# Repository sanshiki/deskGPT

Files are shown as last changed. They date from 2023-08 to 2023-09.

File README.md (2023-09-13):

# 嵌入式高级实验作业：智能桌宠deskGPT

## 项目介绍

### 简介

本项目是浙江大学嵌入式高级实验课程项目，内容为基于stm32的AI智能桌宠deskGPT，能够实现识别用户语音，并转为文字，通过基于chatGPT3.5的大语言模型AI，实现对用户语音的智能回复，并合成语音，通过扬声器播放。

### 模块介绍

#### 下位机

下位机MCU我们采用stm32f407zgt6，使用cubemx+keil5进行编程。录音以及播放模块采用vs1053模块。

#### 上位机

上位机程序我们使用python3.11.4，语音识别（iat）与语音合成（tts）我们采用科大讯飞的web接口，AI模块我们使用的是chatanywhere的开源项目，参考https://github.com/chatanywhere/GPT_API_free.git。

## 依赖安装

### 安装方法

```bash
pip install <package-name>
```

**注意：pywt的安装方法为 `pip install PyWavelets`**

### python第三方库

websocket、numpy、pyusb、openai、pywt、scipy

## 更新日志

23.7.14：建立项目仓库

嵌入式部分：基本参照https://blog.csdn.net/weixin_44226356/article/details/125153210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,239^v2^insert_chatgpt&spm=1018.2226.3001.4187

经测试发现usb_cdc在发送时字节会翻转，故写了一个byteSwap函数

上位机serial：主要是使用了python自带的pyserial库。安装：

```bash
pip install pyserial
```

串口封装为usb_cdc库。

UI部分使用tkinter，还未完成

文件读写封装为fileIO库，主要用的就是pcmFileManager

**已实现的功能**：usb_cdc串口收发，i2s收发，保存为pcm文件

**待解决的问题**：pcm文件的数据不知道正不正确，经过网上找的pcm播放器放出来全是噪音，无法做进一步的滤波处理。

相关csdn链接：
example:https://blog.csdn.net/Laura_Luo/article/details/117779052?spm=1001.2014.3001.5506
usb_cdc:https://blog.csdn.net/zhanglifu3601881/article/details/89441412?spm=1001.2014.3001.5506
inmp441:https://blog.csdn.net/qq_15181569/article/details/131224833?spm=1001.2014.3001.5506
vm8978:https://blog.csdn.net/banzhuan133/article/details/78610883/?spm=1001.2014.3001.5506
i2s:https://blog.csdn.net/Q_Lee/article/details/131217760?spm=1001.2014.3001.5506

23.7.20

usb通信改为使用pyusb库

解决pcm数据格式问题，成功播放出inmp441的录音，但是噪声较大。

尝试过采用带通滤波、小波变换等滤波方法，最后采用小波变换。

经过测试，usb传输数据遗漏严重，暂时不知道如何解决。

科大讯飞的iat、tts模块以及chatGPT api接入均已完成。

23.8：完善项目

解决了usb传输数据遗漏的问题，从单次发送少量数据，快速发送的模式改为单次发送大量数据，降低发送频率，成功解决了数据发送的问题。

基于此，为上下位机编写了数据包以及解包方式。数据包包括用于检测数据的数据头、下位机控制字以及音频数据。

inmp441效果不好，改为使用vs1053，参考正点原子的原代码进行驱动。

成功实现vs1053的录音和播放问题，并且成功串联从录音、iat、tts到播放的模块。

存在问题：vs1053在录音时会播放录到的音频，并且噪声很大。第一次上电时无法正常工作。

23.9

查资料发现，可以通过修改vs1053的SCI_VOL寄存器来使得录音时不播放，但是正点原子例程的atk_mo1053_set_volume修改不了。

后来发现通过修改sram可以实现。参考博客：http://www.openedv.com/posts/list/14900.htm

在上位机初始化之后，提前发送几个进入录音模式的空数据包，能够解决第一次上电无法工作的问题。

成功串联chatGPT模块，并且使程序流程可以循环。

存在问题：合成的语音没有电流声，但是播放时存在电流声。初步猜测是传输间隔的问题。目前的传输间隔由sleep控制，过于粗糙。

Emoji文件夹需要使用opencv编译，能够产生二进制视频文件(240*240*3).

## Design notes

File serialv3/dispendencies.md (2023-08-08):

# 科大讯飞iat & tts接口环境配置

## 依赖库

- websocket

## 存在问题

* 报错：`AttributeError: module 'websocket' has no attribute 'enableTrace'`
*

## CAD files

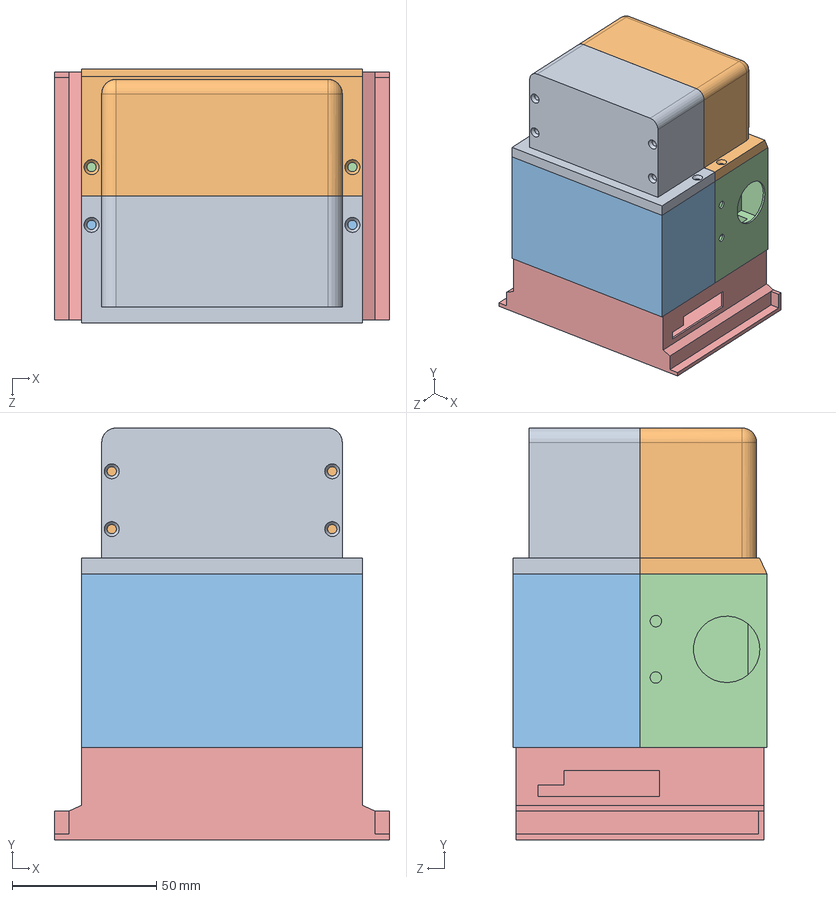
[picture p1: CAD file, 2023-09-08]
3dprint/小对立.SLDASM
116.0 x 142.6 x 88.0 mm
deskGPT底座-stm32
deskGPT中间壳
deskGPT中间壳2
deskGPT头-oled-part1
deskGPT头-part2

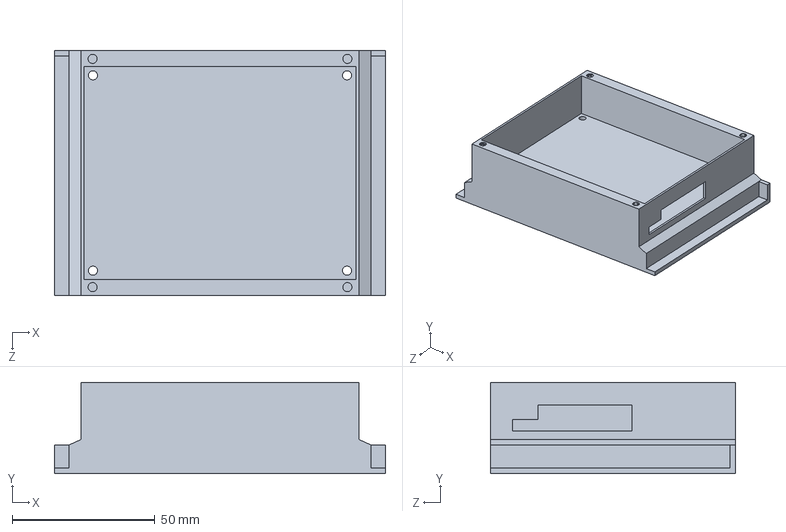
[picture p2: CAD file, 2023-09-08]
3dprint/deskGPT底座-stm32.SLDPRT
116.0 x 32.0 x 86.0 mm

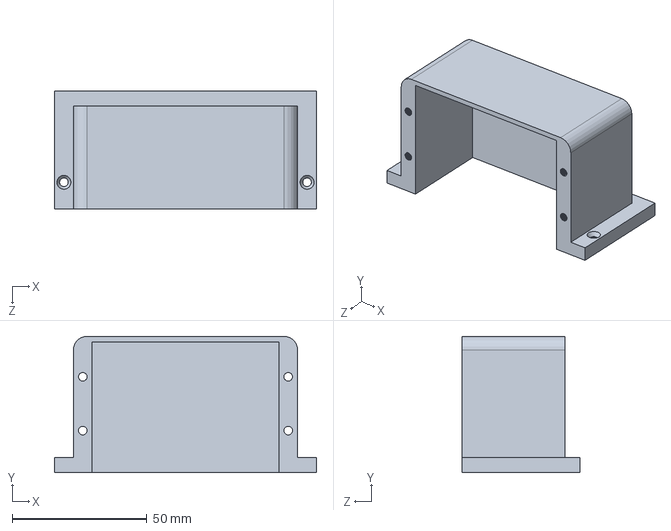
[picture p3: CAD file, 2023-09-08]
3dprint/deskGPT头-part2.SLDPRT
97.3 x 50.6 x 44.0 mm

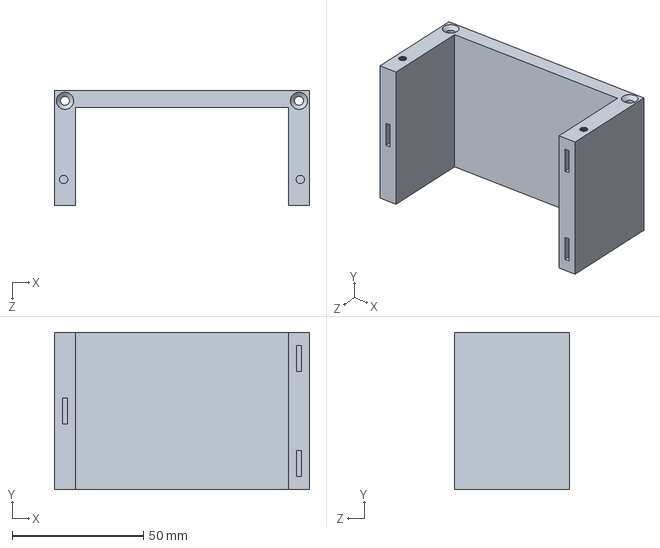
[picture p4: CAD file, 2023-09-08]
3dprint/deskGPT中间壳2.SLDPRT
97.3 x 60.0 x 44.0 mm

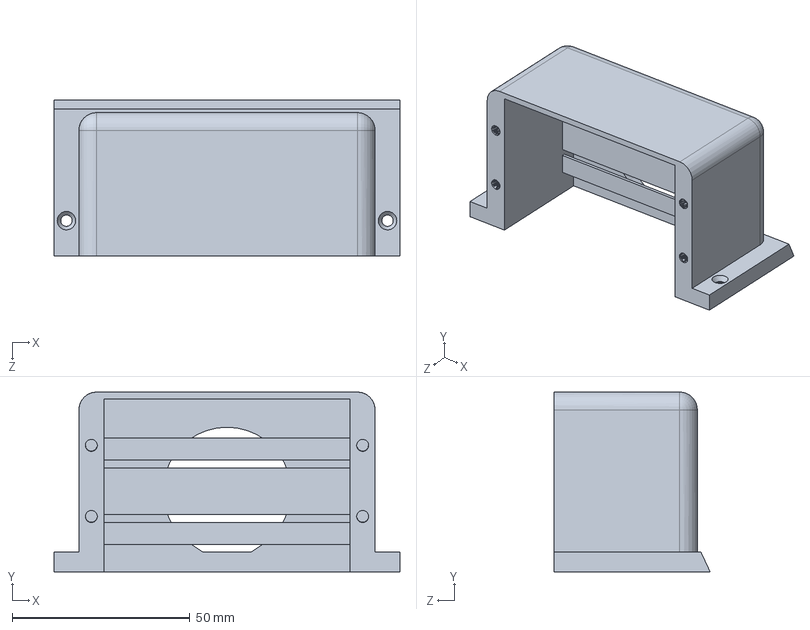
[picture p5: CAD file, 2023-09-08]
3dprint/deskGPT头-oled-part1.SLDPRT
97.3 x 50.6 x 44.0 mm

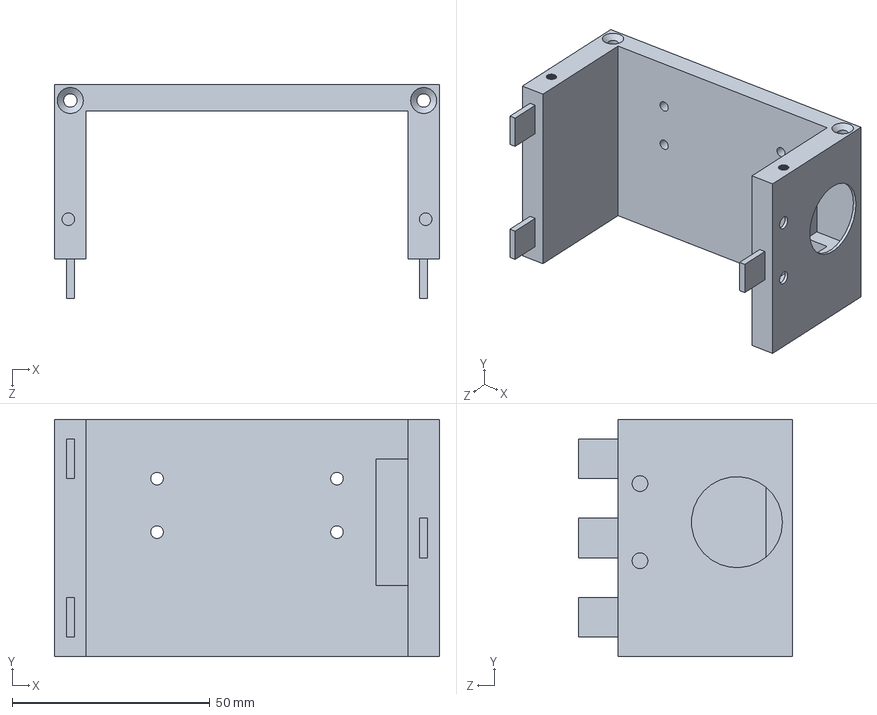
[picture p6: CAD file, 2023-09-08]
3dprint/deskGPT中间壳.SLDPRT
97.3 x 60.0 x 54.0 mm

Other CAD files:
3dprint/deskGPT中间壳.STL
3dprint/deskGPT中间壳2.STL
3dprint/deskGPT头-oled-part1.STL
3dprint/deskGPT头-part2.STL
3dprint/deskGPT底座-stm32.STL

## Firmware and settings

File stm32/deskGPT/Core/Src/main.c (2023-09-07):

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
/* Includes ------------------------------------------------------------------*/
#include "main.h"
#include "spi.h"
#include "usart.h"
#include "usb_device.h"
#include "gpio.h"

/* USER CODE BEGIN Includes */
#include "atk_mo1053.h"
#include "delay.h"
#include <string.h>
#include "recorder.h"
#include "dataPackDecode.h"
#include "dataQueue.h"
#include "usbd_cdc_if.h"
/* USER CODE END Includes */


/* USER CODE BEGIN PV */
uint16_t send_buf[275]; //100
uint8_t recv_buf[DATA_SIZE];
uint8_t audio_buf[AUDIO_DATA_BUF_SIZE];
uint8_t flg = 0;
extern usb_datapack_decode_t pcDataPack;

uint8_t rec_state = PLAY_MODE;

/* USER CODE END PV */

void SystemClock_Config(void);
/* USER CODE BEGIN 0 */
uint8_t CDC_Transmit_One_Byte(uint16_t byte)
{
    static uint16_t cnt = 0;

    send_buf[cnt++] = byte;
    if (cnt == 275)
    {
        CDC_Transmit_FS((uint8_t *)send_buf, 550);
        cnt = 0;
    }
    // for(int i=0;i<100;i++)
    // {
    //     send_buf[i] = byte;
    // }
    // CDC_Transmit_FS((uint8_t *)send_buf, 200);
}

// void playSpeakerTest(void)
// {
//     HAL_DAC_Start(&hdac,DAC_CHANNEL_1);
//                 // for(int i=0;i<AUDIO_DATA_SIZE;i+=2)
//                 // {
//                 //     uint16_t audio_data = (uint16_t)audio_buf[i]<<8 | (uint16_t)audio_buf[i+1];
//                 //     HAL_DAC_SetValue(&hdac,DAC_CHANNEL_1,DAC_ALIGN_12B_R,audio_data);
//                 //     // HAL_Delay(1);
//                 // }
//     static uint16_t val = 0;
//     HAL_DAC_SetValue(&hdac,DAC_CHANNEL_1,DAC_ALIGN_12B_R,val);
//     val += 2;
//     if(val == 4096)
//     {
//         val = 0;
//     }
//     HAL_DAC_Stop(&hdac,DAC_CHANNEL_1);
// }

// void playSpeaker(uint32_t audio_data)
// {
//     HAL_DAC_Start(&hdac,DAC_CHANNEL_1);
//     HAL_DAC_SetValue(&hdac,DAC_CHANNEL_1,DAC_ALIGN_12B_R,audio_data);
//     HAL_DAC_Stop(&hdac,DAC_CHANNEL_1);
// }
/* USER CODE END 0 */

/**
  * @brief  The application entry point.
  * @retval int
  */
int main(void)
{
  /* MCU Configuration--------------------------------------------------------*/

  /* Reset of all peripherals, Initializes the Flash interface and the Systick. */
  HAL_Init();

  /* USER CODE BEGIN Init */
    dataPackInit(&pcDataPack);
    pcDataQueueInit();
    audioDataQueueInit();
  /* USER CODE END Init */

  /* Configure the system clock */
  SystemClock_Config();

  /* Initialize all configured peripherals */
  MX_GPIO_Init();
  MX_USB_DEVICE_Init();
  MX_SPI1_Init();
  MX_UART4_Init();
  /* Infinite loop */
  /* USER CODE BEGIN WHILE */
    atk_mo1053_init();
    atk_mo1053_reset();
    atk_mo1053_soft_reset();
    atk_mo1053_restart_play();
    uint16_t cnt = 0;
    uint16_t idx = 0;
    while (1)
    {
        HAL_UART_Transmit(&huart4, &rec_state, 1, 100);
    /* USER CODE END WHILE */

    /* USER CODE BEGIN 3 */

        /* get audio data from spi and send to usb */
        if (pcDataPack.record_enable && !pcDataPack.play_enable)    //录音
        {
            if(rec_state != RECORD_MODE)
            {
                atk_mo1053_reset();
                atk_mo1053_soft_reset();
                recoder_enter_rec_mode(0);
				atk_mo1053_set_volume(0x00);
                rec_state = RECORD_MODE;
                delay_ms(10);
            }
            if (atk_mo1053_read_reg(SPI_HDAT1))
            {
                uint16_t data = atk_mo1053_read_reg(SPI_HDAT0);
                cnt++;
                // send_buf[idx++] = cnt;
                send_buf[idx++] = data;
                // send_buf[idx++] = 0;
                if (idx == 100)
                {
                    CDC_Transmit_FS((uint8_t *)send_buf, 200);
                    idx = 0;
                }
            }
        }
        else if (!pcDataPack.record_enable && pcDataPack.play_enable)   //播放
        {
            if(rec_state != PLAY_MODE)
            {
                atk_mo1053_reset();
                atk_mo1053_soft_reset();
                atk_mo1053_restart_play();
                atk_mo1053_set_all();
                atk_mo1053_reset_decode_time();
                atk_mo1053_spi_speed_high();
                atk_mo1053_write_cmd(SPI_AICTRL0,8000);	//设置采样�?,设置�?16Khz
                atk_mo1053_write_cmd(SPI_CLOCKF,0X2000);	//设置VS10XX的时�?,MULT:2倍频;ADD:不允�?;CLK:12.288Mhz	
                rec_state = PLAY_MODE;
                delay_ms(10);
            }
            
            getAudioData(audio_buf, recv_buf, &pcDataPack);
            for(int i=0;i<AUDIO_DATA_BUF_SIZE;i+=AUDIO_DATA_SIZE)
            {
                uint16_t timeout_cnt = 0;
                //防止发�?�失败，导致程序卡死
                while(atk_mo1053_send_music_data(audio_buf+i))
                {
                    timeout_cnt++;
                    if(timeout_cnt > 10000)
                    {
                        break;
                    }
                }
            }
        }
        else    //停止
        {
            if(rec_state != STOP_MODE)
            {
                atk_mo1053_reset();
                atk_mo1053_set_volume(0x00);
                rec_state = STOP_MODE;
            }
        }

        /* get pc data from usb */
        if (!pcDataQueueIsEmpty())
        {
            pcDataQueuePop(recv_buf, DATA_SIZE);

            if (checkDataHead(recv_buf, &pcDataPack))
            {
                checkSpiCtrl(recv_buf, &pcDataPack);
            }
        }
    }
  /* USER CODE END 3 */
}

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


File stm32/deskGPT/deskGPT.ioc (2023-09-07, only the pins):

Mcu.UserName=STM32F407ZGTx
PA11.Signal=USB_OTG_FS_DM
PA12.Signal=USB_OTG_FS_DP
PA13.Signal=SYS_JTMS-SWDIO
PA14.Signal=SYS_JTCK-SWCLK
PA5.GPIO_Label=SPI1_SCK
PA5.Signal=SPI1_SCK
PA6.GPIO_Label=SPI1_SO
PA6.Signal=SPI1_MISO
PA7.GPIO_Label=SPI1_SI
PA7.Signal=SPI1_MOSI
PB10.GPIO_Label=VS10XX_XCS
PB10.Signal=GPIO_Output
PB11.GPIO_Label=VS10XX_XDCS
PB11.Signal=GPIO_Output
PB13.GPIO_Label=I2S2_CK
PB13.Signal=I2S2_CK
PC0.GPIO_Label=VS10XX_RST
PC0.Signal=GPIO_Output
PC10.Signal=UART4_TX
PC11.Signal=UART4_RX
PF6.GPIO_Label=VS10XX_DQ
PF6.Signal=GPIO_Input
PH0-OSC_IN.Signal=RCC_OSC_IN
PH1-OSC_OUT.Signal=RCC_OSC_OUT

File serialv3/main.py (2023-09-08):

from moudule import iat
from moudule import tts
from moudule import usb_cdc
from moudule import fileIO
from moudule import sampling
from moudule import bytetools
from moudule import datapack
from moudule import pcm2wav
from moudule import filter
from moudule import chatGPT

from time import sleep,time
import wave
import threading
import usb.core
from queue import Queue
import soundfile as sf

# 指定 PCM 文件路径
pcm_file = 'audioFile/pcmFile/output.pcm'
filtered_pcm_file = 'audioFile/pcmFile/filtered_output.pcm'
play_pcm_file = 'audioFile/pcmFile/demo.pcm'

# 指定 WAV 文件路径
wav_file = 'audioFile/wavFile/output.wav'
filtered_wav_file = 'audioFile/wavFile/filtered_output.wav'
play_wav_file = 'audioFile/wavFile/demo.wav'

# 科大讯飞认证信息
APPID = '6267d3f7'
APISecret = 'ZDRlMDQwMmZjNGJiOTBhYTc5ZWIxY2Ex'
APIKey = '29cd024f42b3faa5e6c15303cf304bc1'
AudioFile = r'demo.pcm'

# 配置音频参数
sample_width = 2  # 采样宽度（字节数）
sample_rate = 16000  # 采样率
channels = 1  # 声道数

# 缓冲队列
q = Queue()

# usb-cdc
vid = 0x0483
pid = 0x5740

usb_device = None
try:# 初始化usb-cdc
    usb_device = usb_cdc.USB_CDC(vid, pid)
except ValueError as e:
    print(e)
    exit()

# 数据包
pcDataPack = datapack.dataPack()
    
# 标志位
err_flag = False
record_flag = True
no_voice_flag = False

# usb-cdc线程函数
def usb_cdc_thread():
    global err_flag
    global record_flag

    print("usb_cdc_thread start")

    while record_flag == True and err_flag == False and no_voice_flag == False:
        try:
            pcDataPack.record_enable = True
            pcDataPack.play_enable = False
            pcDataPack.update()
            usb_device.usb_send_data(pcDataPack.bin) # 发送数据包
            raw_data = usb_device.usb_read_data(200) # 读取数据
            if raw_data:
                q.put(raw_data)

        except Exception as e:
            print(e)
            err_flag = True



def getDataFromMircophone():
    # 打开文件
    txtFile = fileIO.txtFileManager("wave_data.txt")
    
    # 声音记录
    output_file = wave.open(pcm_file, 'wb')
    output_file.setsampwidth(sample_width)
    output_file.setframerate(sample_rate)
    output_file.setnchannels(channels)

    # 变量初始化
    txtFile.open()
    wait_time = time()

    # 采样初始化
    sampling_datav2 = sampling.samplingDatav2(30,100)

    # 标志位初始化
    global err_flag
    global record_flag
    global no_voice_flag

    record_flag = True
    err_flag = False
    no_voice_flag = False

    #开启usb-cdc线程
    t = threading.Thread(target=usb_cdc_thread)
    t.start()

    # 记录时间
    record_time = time()
    no_voice_time = time()

    while True:
        size = q.qsize()    # 获取队列长度

        if sampling_datav2.is_voice:#有声音
            no_voice_time = time()

        if time() - record_time > 10:#录音超过10秒
            record_flag = False
            break

        if  time() - no_voice_time > 3:#3秒没声音
            record_flag = False
            if abs(record_time - no_voice_time) < 0.01:
                print("no voice for 3 seconds from the beginning")
                no_voice_flag = True
            else:
                print("no voice for 3 seconds")
            break

        if err_flag == True:    # 线程出错
            print("error occured")
            break

        if size != 0:
            raw_data = q.get()
            if raw_data:
                try:
                    # 数据初始化
                    byte_data = b''
                    byte_data_list = []
                    dec_data_str_list = []
                    dec_data_list = []
                    hex_data_str_list = []
                    cnt = 0
                    for i in raw_data:
                        #将i转为byte
                        byte_data += bytes([i])
                        cnt += 1
                        if cnt == 2:# 每2个字节为一组
                            byte_data_list.append(byte_data)
                            cnt = 0


                            # 转为10进制
                            dec_data_str = bytetools.byte2int(byte_data)
                            dec_data_list.append(abs(int(dec_data_str)))
                            dec_data_str_list.append(dec_data_str)

                            # 转为16进制
                            hex_data_str = hex(dec_data_str)
                            hex_data_str_list.append(hex_data_str)
    
                            # 打印信息
                            # print("hex_data_str:",hex_data_str)
                            # print("dec_data_str:",dec_data_str)
                            # print("byte_data:",byte_data)

                            # 将音频数据写入PCM文件
                            # 写两遍，因为是单声道
                            output_file.writeframes(byte_data)
                            output_file.writeframes(byte_data)
                            #写入txt文件
                            txtFile.write(str(int(dec_data_str)) + " ")

                            byte_data = b''
                    # 样本更新
                    sampling_datav2.update(dec_data_list)
                except Exception as e:
                    print(e)
                    err_flag = True
                    break

            else: #wait
                if time() - wait_time > 5:
                    print("wait too long")
                    break
        else:
            pass

    # 关闭PCM文件
    output_file.close()
    txtFile.close()
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

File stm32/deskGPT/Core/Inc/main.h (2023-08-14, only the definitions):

#define VS10XX_DQ_Pin GPIO_PIN_6
#define VS10XX_DQ_GPIO_Port GPIOF
#define VS10XX_RST_Pin GPIO_PIN_0
#define VS10XX_RST_GPIO_Port GPIOC
#define SPI1_SCK_Pin GPIO_PIN_5
#define SPI1_SCK_GPIO_Port GPIOA
#define SPI1_SO_Pin GPIO_PIN_6
#define SPI1_SO_GPIO_Port GPIOA
#define SPI1_SI_Pin GPIO_PIN_7
#define SPI1_SI_GPIO_Port GPIOA
#define VS10XX_XCS_Pin GPIO_PIN_10
#define VS10XX_XCS_GPIO_Port GPIOB
#define VS10XX_XDCS_Pin GPIO_PIN_11
#define VS10XX_XDCS_GPIO_Port GPIOB
#define I2S2_CK_Pin GPIO_PIN_13
#define I2S2_CK_GPIO_Port GPIOB

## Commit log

2023-08-07 add serialv3 and set up vs1053 test based on stm32f407.
2023-09-07 update chatGPT socket
2023-09-08 update 3d model
    [deskGPT中间壳.SLDPRT, deskGPT中间壳2.SLDPRT, deskGPT头-oled-part1.SLDPRT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]
2023-09-09 update stl
    [deskGPT中间壳.STL, deskGPT中间壳2.STL, deskGPT头-oled-part1.STL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]

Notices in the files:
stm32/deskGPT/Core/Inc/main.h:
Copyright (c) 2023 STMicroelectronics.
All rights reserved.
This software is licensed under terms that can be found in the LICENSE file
